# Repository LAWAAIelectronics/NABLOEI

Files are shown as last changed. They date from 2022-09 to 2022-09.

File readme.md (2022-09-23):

# ReadMe #
This repository provides:
- the full KiCad project, including gerbers plotted to the specifications of JLCPCB
- a PDF of the schematic for those who do not use KiCad
- the Arduino code
- a PNG of the user manual like bellow

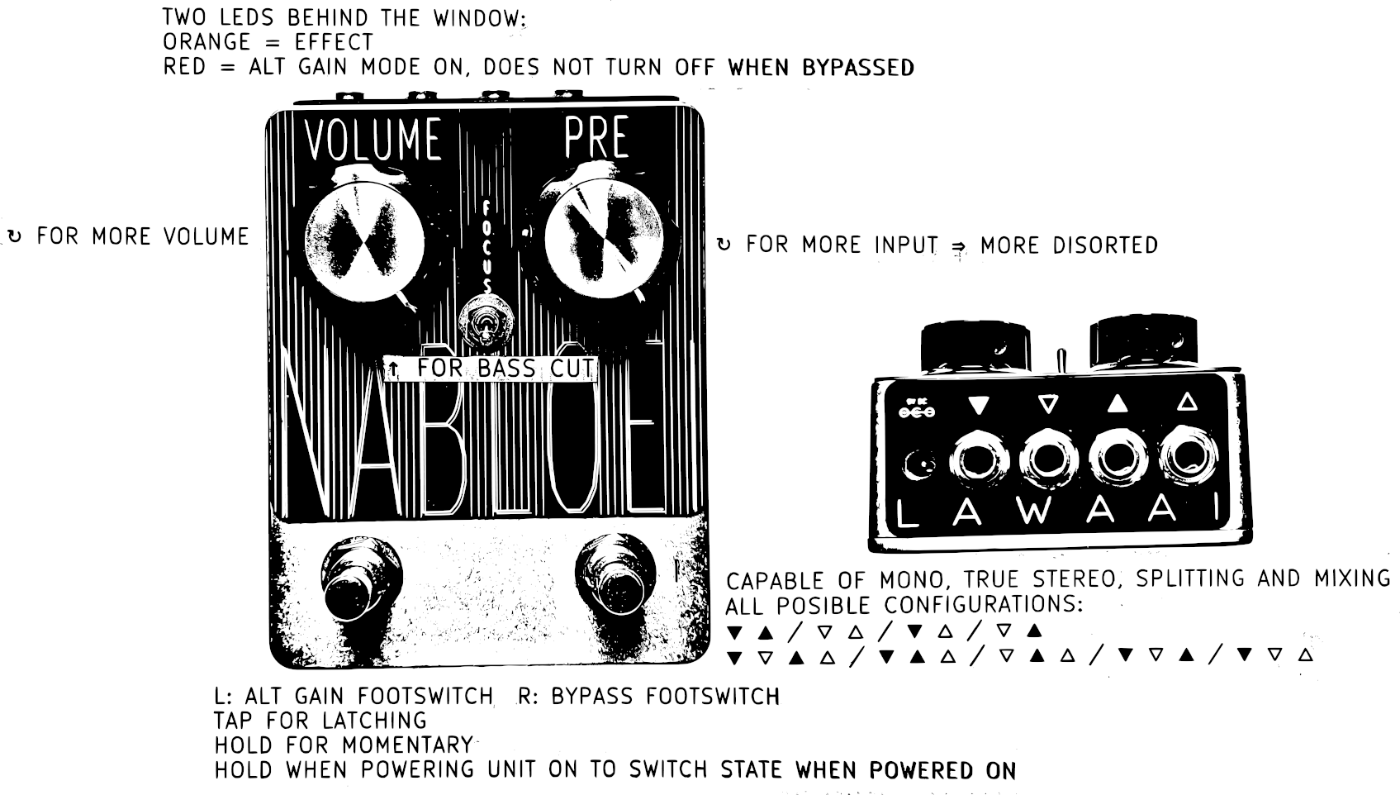
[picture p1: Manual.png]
Manual


The gerbers, pdf schematic and firmware are not located under the code tab but can be downloaded in releases.

All of this documentation is free for you to use, all I ask is that no direct copies of this pedal are made for sale.

Thank you.

LAWAAI

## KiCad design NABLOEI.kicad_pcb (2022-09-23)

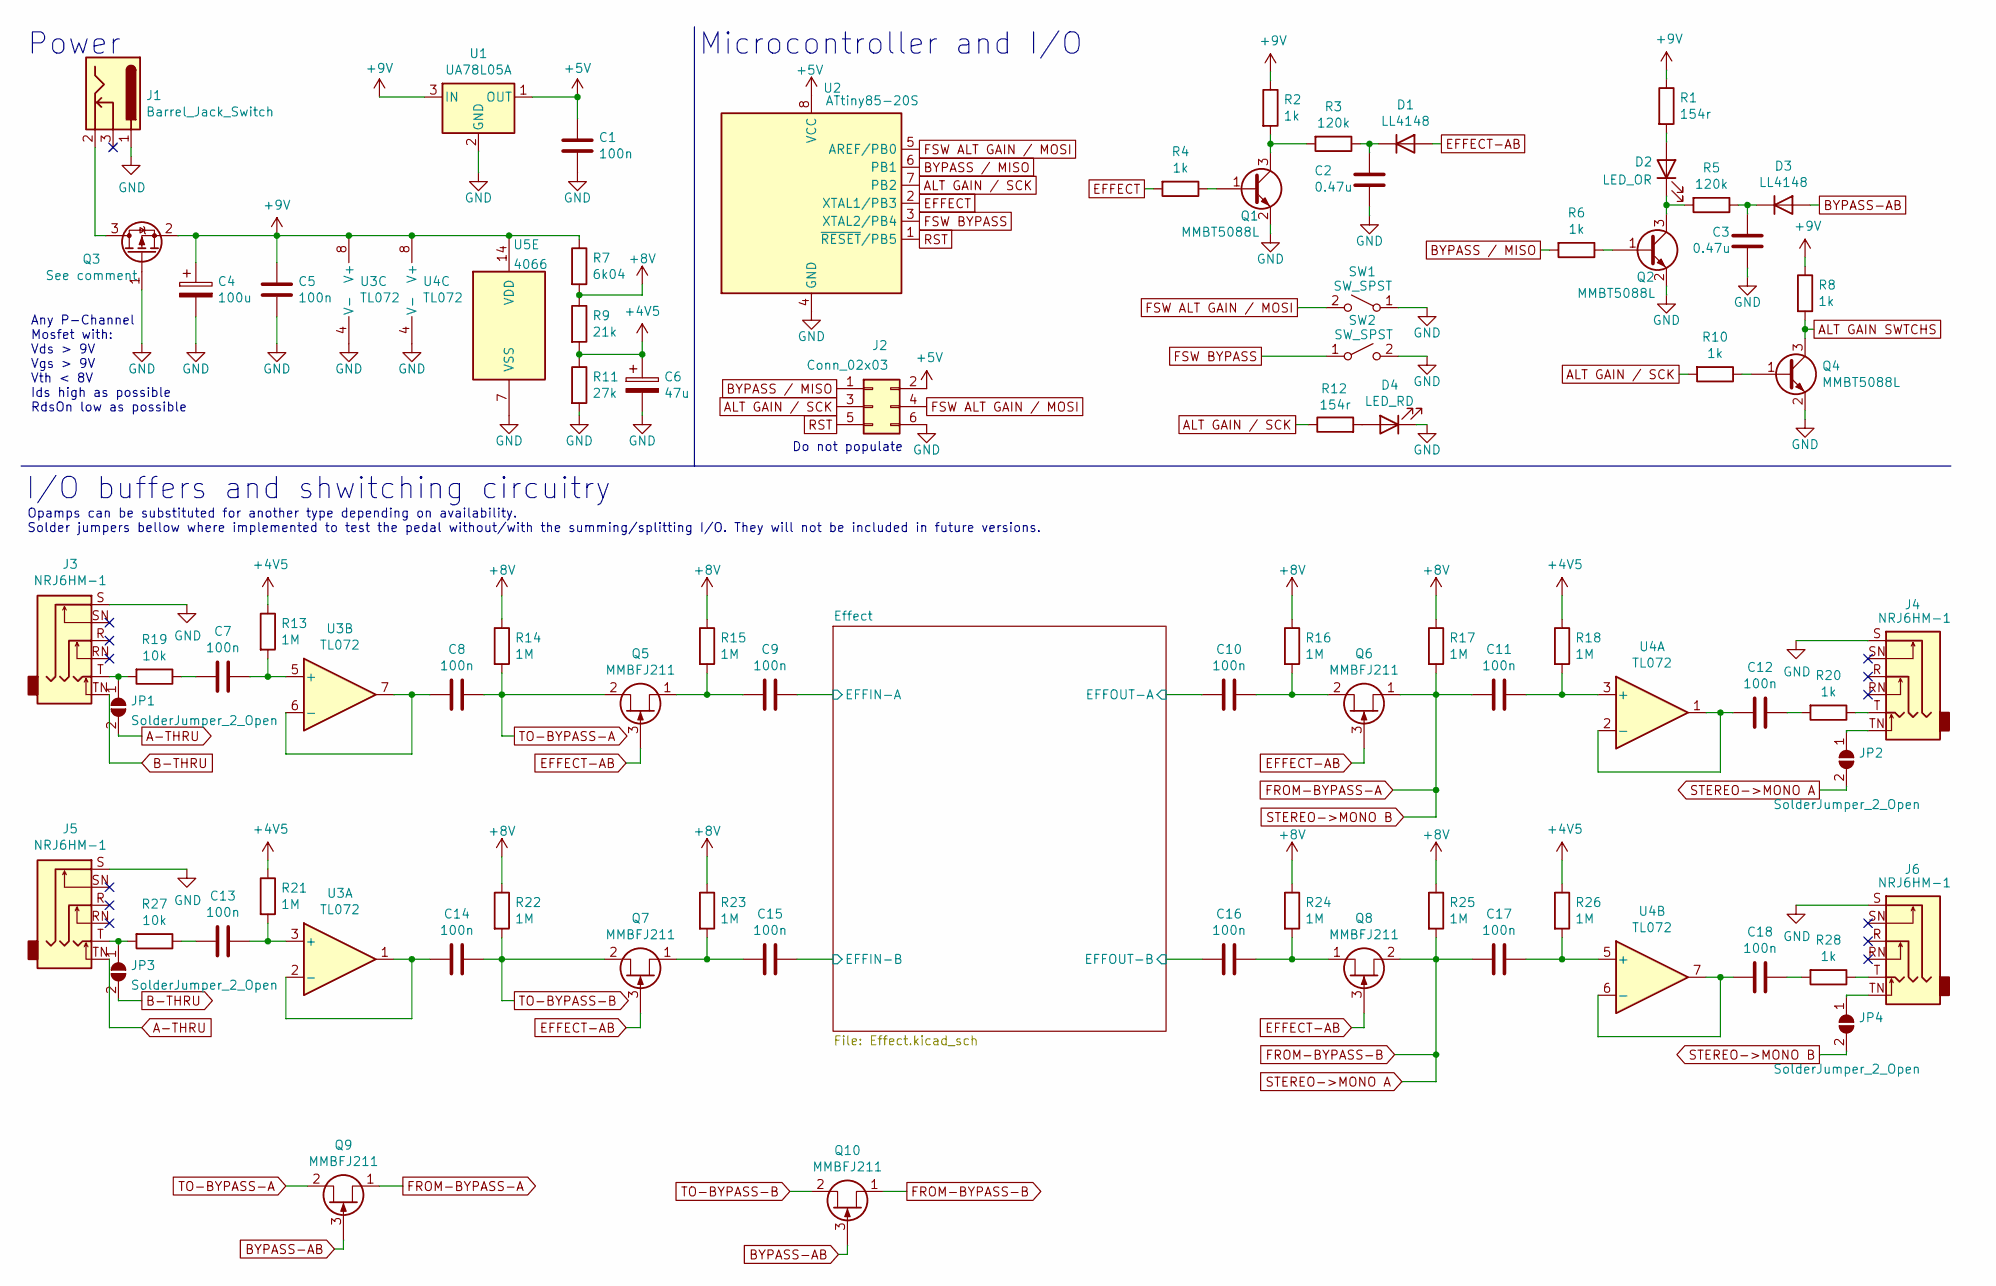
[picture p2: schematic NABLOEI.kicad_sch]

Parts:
C1, C5, C7, C8, C9, C10, C11, C12, C13, C14, C15, C16, C17, C18: 100n; C_1206_3216Metric
C2, C3: 0.47u; C_1206_3216Metric
C4: 100u; CP_Elec_8x5.4
C6: 47u; CP_Elec_5x5.4
D1, D3: LL4148; D_MiniMELF
D2: LED_OR; LED_1206_3216Metric
D4: LED_RD; LED_1206_3216Metric
J1: Barrel_Jack_Switch; BarrelJack_Horizontal
J2: Conn_02x03; PinHeader_2x03_P2.54mm_Vertical
J3, J4, J5, J6: NRJ6HM-1; Jack_6.35mm_Neutrik_NRJ6HM-1_Horizontal
JP1, JP2, JP3, JP4: SolderJumper_2_Open; SolderJumper-2_P1.3mm_Open_RoundedPad1.0x1.5mm
Q1, Q2, Q4: MMBT5088L; SOT-23
Q3: See comment; SOT-23
Q5, Q6, Q7, Q8, Q9, Q10: MMBFJ211; SOT-23
R1, R12: 154r; R_1206_3216Metric
R2, R4, R6, R8, R10, R20, R28: 1k; R_1206_3216Metric
R3, R5: 120k; R_1206_3216Metric
R7: 6k04; R_1206_3216Metric
R9: 21k; R_1206_3216Metric
R11: 27k; R_1206_3216Metric
R13, R14, R15, R16, R17, R18, R21, R22, R23, R24, R25, R26: 1M; R_1206_3216Metric
R19, R27: 10k; R_1206_3216Metric
SW1, SW2: SW_SPST; Molex_Micro-Latch_53254-0270_1x02_P2.00mm_Horizontal
U1: UA78L05A; SOT-89-3
U2: ATtiny85-20S; SOIC-8W_5.3x5.3mm_P1.27mm
U3, U4: TL072; SOIC-8W_5.3x5.3mm_P1.27mm
U5: 4066; SOIC-14_3.9x8.7mm_P1.27mm

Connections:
+4V5: C6.1, R9.2, R11.1, R13.1, R18.1, R21.1, R26.1
+5V: C1.1, J2.2, U1.1 (OUT), U2.8 (VCC)
+8V: R7.2, R9.1, R14.1, R15.1, R16.1, R17.1, R22.1, R23.1, R24.1, R25.1
+9V: C4.1, C5.1, Q3.2 (S), R1.1, R2.1, R7.1, R8.1, U1.3 (IN), U3.8 (V+), U4.8 (V+), U5.14 (VDD); also elsewhere on the board
/Effect/EFFIN-A: C9.1; also elsewhere on the board
/Effect/EFFIN-B: C15.1; also elsewhere on the board
/Effect/EFFOUT-A: C10.2; also elsewhere on the board
/Effect/EFFOUT-B: C16.2; also elsewhere on the board
A-THRU: J5.TN, JP1.2 (B)
ALT GAIN SWTCHS: Q4.3 (C), R8.2; also elsewhere on the board
ALT GAIN / SCK: J2.3, R10.2, R12.1, U2.7 (PB2)
B-THRU: J3.TN, JP3.2 (B)
BYPASS / MISO: J2.1, R6.2, U2.6 (PB1)
BYPASS-AB: D3.2 (A), Q9.3 (G), Q10.3 (G)
EFFECT: R4.2, U2.2 (XTAL1/PB3)
EFFECT-AB: D1.2 (A), Q5.3 (G), Q6.3 (G), Q7.3 (G), Q8.3 (G)
FROM-BYPASS-A: C11.2, JP4.2 (B), Q6.1 (S), Q9.1 (S), R17.2
FROM-BYPASS-B: C17.2, JP2.2 (B), Q8.2 (D), Q10.1 (S), R25.2
FSW ALT GAIN / MOSI: J2.4, SW1.2 (B), U2.5 (AREF/PB0)
FSW BYPASS: SW2.1 (A), U2.3 (XTAL2/PB4)
GND: C1.2, C2.2, C3.2, C4.2, C5.2, C6.2, D4.1 (K), J1.1, J2.6, J3.S, J4.S, J5.S, J6.S, Q1.2 (E), Q2.2 (E), Q3.1 (G), Q4.2 (E), R11.2, SW1.1 (A), SW2.2 (B), U1.2 (GND), U2.4 (GND), U3.4 (V-), U4.4 (V-), U5.7 (VSS); also elsewhere on the board
unnamed: C2.1, D1.1 (K), R3.1
unnamed: C3.1, D3.1 (K), R5.1
unnamed: C7.1, R13.2, U3.5 (+)
unnamed: C7.2, R19.1
unnamed: C8.2, U3.6 (-), U3.7
unnamed: C9.2, Q5.1 (S), R15.2
unnamed: C10.1, Q6.2 (D), R16.2
unnamed: C11.1, R18.2, U4.3 (+)
unnamed: C12.1, R20.2
unnamed: C12.2, U4.1, U4.2 (-)
unnamed: C13.1, R21.2, U3.3 (+)
unnamed: C13.2, R27.1
unnamed: C14.2, U3.1, U3.2 (-)
unnamed: C15.2, Q7.1 (S), R23.2
unnamed: C16.1, Q8.1 (S), R24.2
unnamed: C17.1, R26.2, U4.5 (+)
unnamed: C18.1, R28.2
unnamed: C18.2, U4.6 (-), U4.7
unnamed: D2.1 (K), Q2.3 (C), R5.2
unnamed: D2.2 (A), R1.2
unnamed: D4.2 (A), R12.2
unnamed: J1.2, Q3.3 (D)
unnamed: J3.T, JP1.1 (A), R19.2
unnamed: J4.T, R20.1
unnamed: J4.TN, JP2.1 (A)
unnamed: J5.T, JP3.1 (A), R27.2
unnamed: J6.T, R28.1
unnamed: J6.TN, JP4.1 (A)
unnamed: Q1.1 (B), R4.1
unnamed: Q1.3 (C), R2.2, R3.2
unnamed: Q2.1 (B), R6.1
unnamed: Q4.1 (B), R10.1
RST: J2.5, U2.1 (~RESET/PB5)
TO-BYPASS-A: C8.1, Q5.2 (D), Q9.2 (D), R14.2
TO-BYPASS-B: C14.1, Q7.2 (D), Q10.2 (D), R22.2

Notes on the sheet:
Microcontroller and I/O
Any P-Channel Mosfet with: Vds > 9V Vgs > 9V Vth < 8V Ids high as possible RdsOn low as possible
Do not populate
Opamps can be substituted for another type depending on availability. Solder jumpers bellow where implemented to test the pedal without/with the summing/splitting I/O. They will not be included in future versions.
I/O buffers and shwitching circuitry
Power

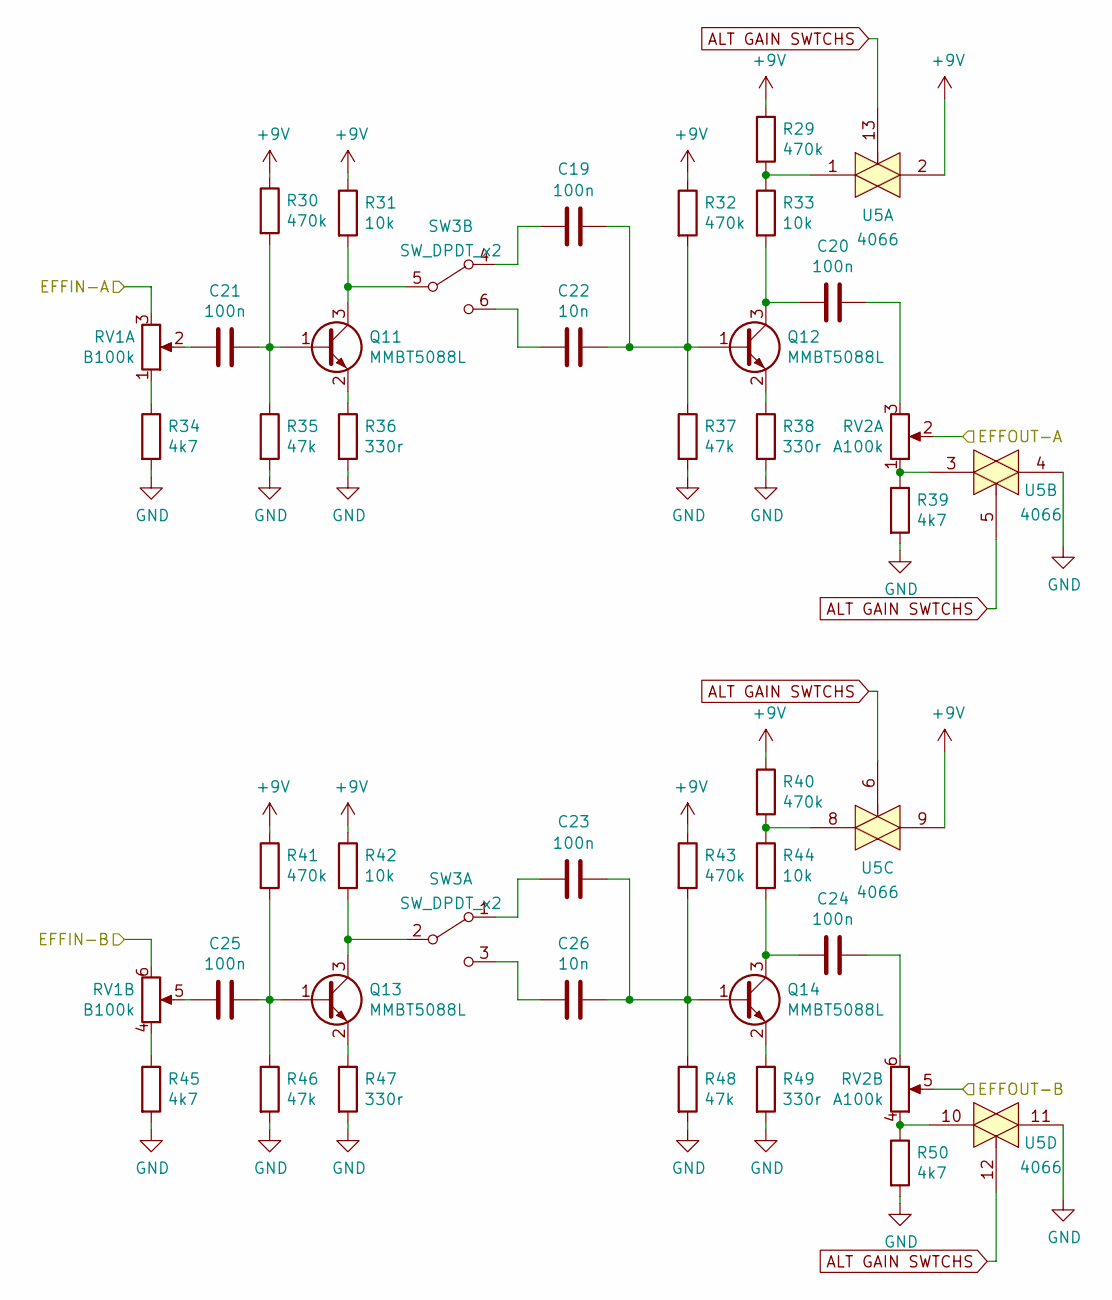
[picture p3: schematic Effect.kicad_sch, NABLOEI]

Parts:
C19, C20, C21, C23, C24, C25: 100n; C_1206_3216Metric
C22, C26: 10n; C_1206_3216Metric
Q11, Q12, Q13, Q14: MMBT5088L; SOT-23
R29, R30, R32, R40, R41, R43: 470k; R_1206_3216Metric
R31, R33, R42, R44: 10k; R_1206_3216Metric
R34, R39, R45, R50: 4k7; R_1206_3216Metric
R35, R37, R46, R48: 47k; R_1206_3216Metric
R36, R38, R47, R49: 330r; R_1206_3216Metric
RV1: B100k; Potentiometer_Alpha_RV16A01F-41-15R1_Dual_Vertical
RV2: A100k; Potentiometer_Alpha_RV16A01F-41-15R1_Dual_Vertical
SW3: SW_DPDT_x2; Switch_Dailywell_Electronics_1MD1T1B1M1QES_DPDT_ON-ON
U5: 4066; SOIC-14_3.9x8.7mm_P1.27mm

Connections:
+9V: R29.1, R30.1, R31.1, R32.1, R40.1, R41.1, R42.1, R43.1, U5.2, U5.9; also elsewhere on the board
/Effect/EFFIN-A: RV1.3; also elsewhere on the board
/Effect/EFFIN-B: RV1.6; also elsewhere on the board
/Effect/EFFOUT-A: RV2.2; also elsewhere on the board
/Effect/EFFOUT-B: RV2.5; also elsewhere on the board
ALT GAIN SWTCHS: U5.5, U5.6, U5.12, U5.13; also elsewhere on the board
GND: R34.2, R35.2, R36.2, R37.2, R38.2, R39.2, R45.2, R46.2, R47.2, R48.2, R49.2, R50.2, U5.4, U5.11; also elsewhere on the board
unnamed: C19.1, C22.1, Q12.1 (B), R32.2, R37.1
unnamed: C19.2, SW3.4 (A)
unnamed: C20.1, RV2.3
unnamed: C20.2, Q12.3 (C), R33.2
unnamed: C21.1, Q11.1 (B), R30.2, R35.1
unnamed: C21.2, RV1.2
unnamed: C22.2, SW3.6 (C)
unnamed: C23.1, C26.1, Q14.1 (B), R43.2, R48.1
unnamed: C23.2, SW3.1 (A)
unnamed: C24.1, RV2.6
unnamed: C24.2, Q14.3 (C), R44.2
unnamed: C25.1, Q13.1 (B), R41.2, R46.1
unnamed: C25.2, RV1.5
unnamed: C26.2, SW3.3 (C)
unnamed: Q11.2 (E), R36.1
unnamed: Q11.3 (C), R31.2, SW3.5 (B)
unnamed: Q12.2 (E), R38.1
unnamed: Q13.2 (E), R47.1
unnamed: Q13.3 (C), R42.2, SW3.2 (B)
unnamed: Q14.2 (E), R49.1
unnamed: R29.2, R33.1, U5.1
unnamed: R34.1, RV1.1
unnamed: R39.1, RV2.1, U5.3
unnamed: R40.2, R44.1, U5.8
unnamed: R45.1, RV1.4
unnamed: R50.1, RV2.4, U5.10

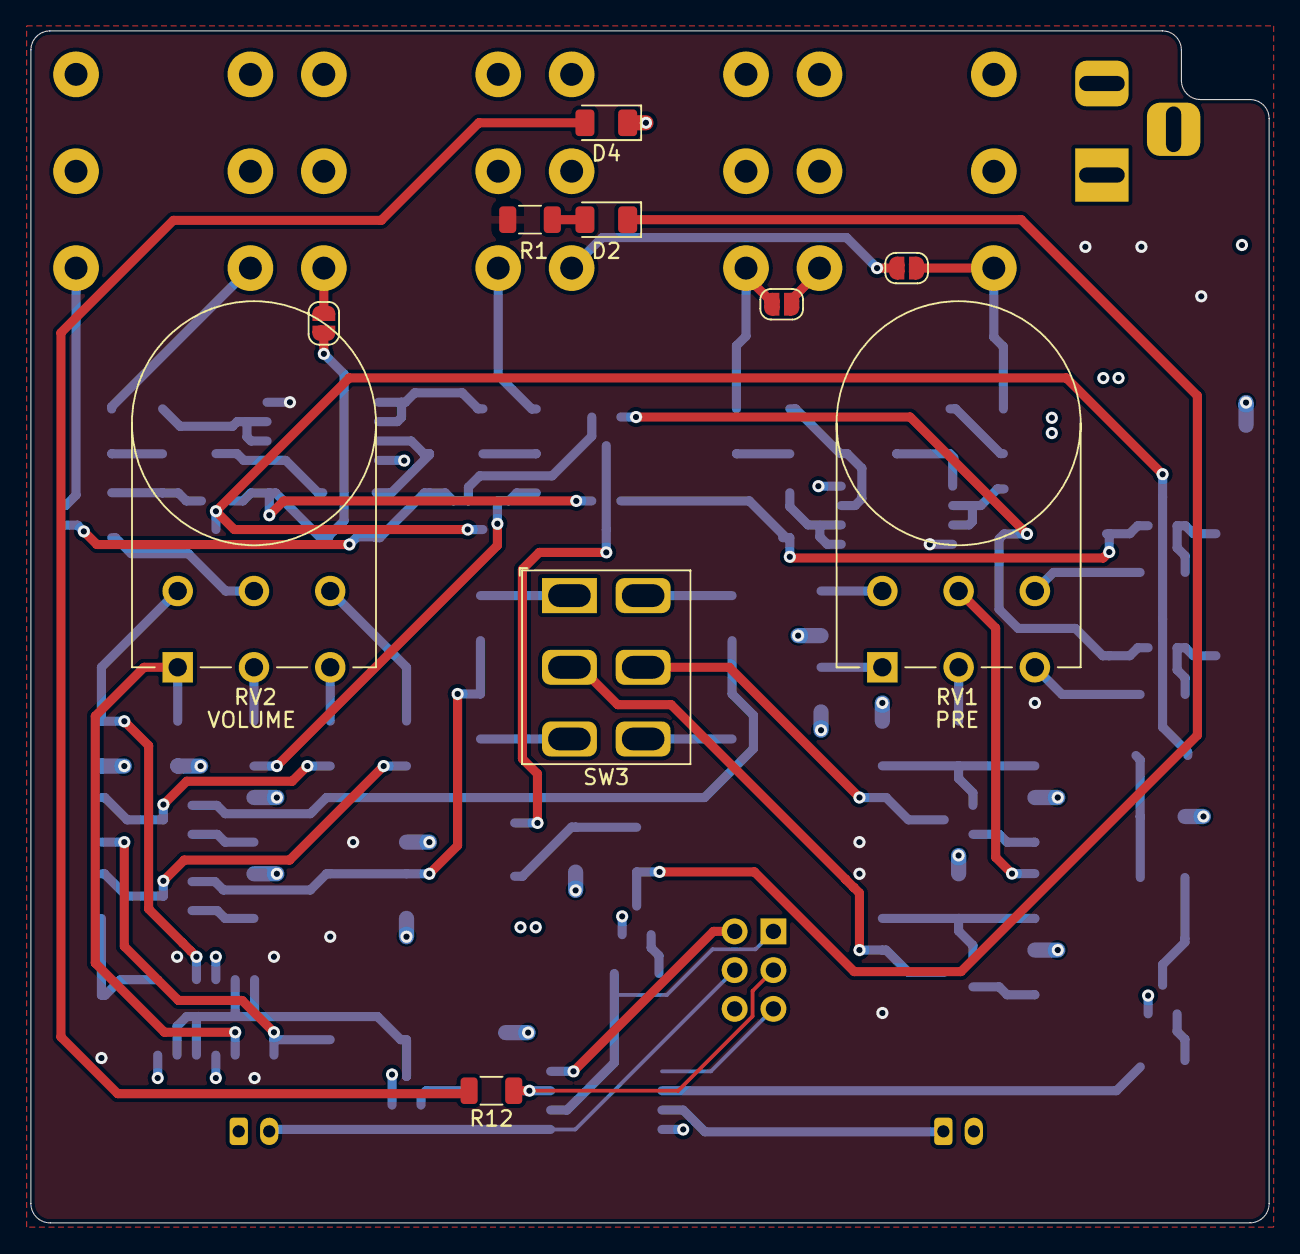
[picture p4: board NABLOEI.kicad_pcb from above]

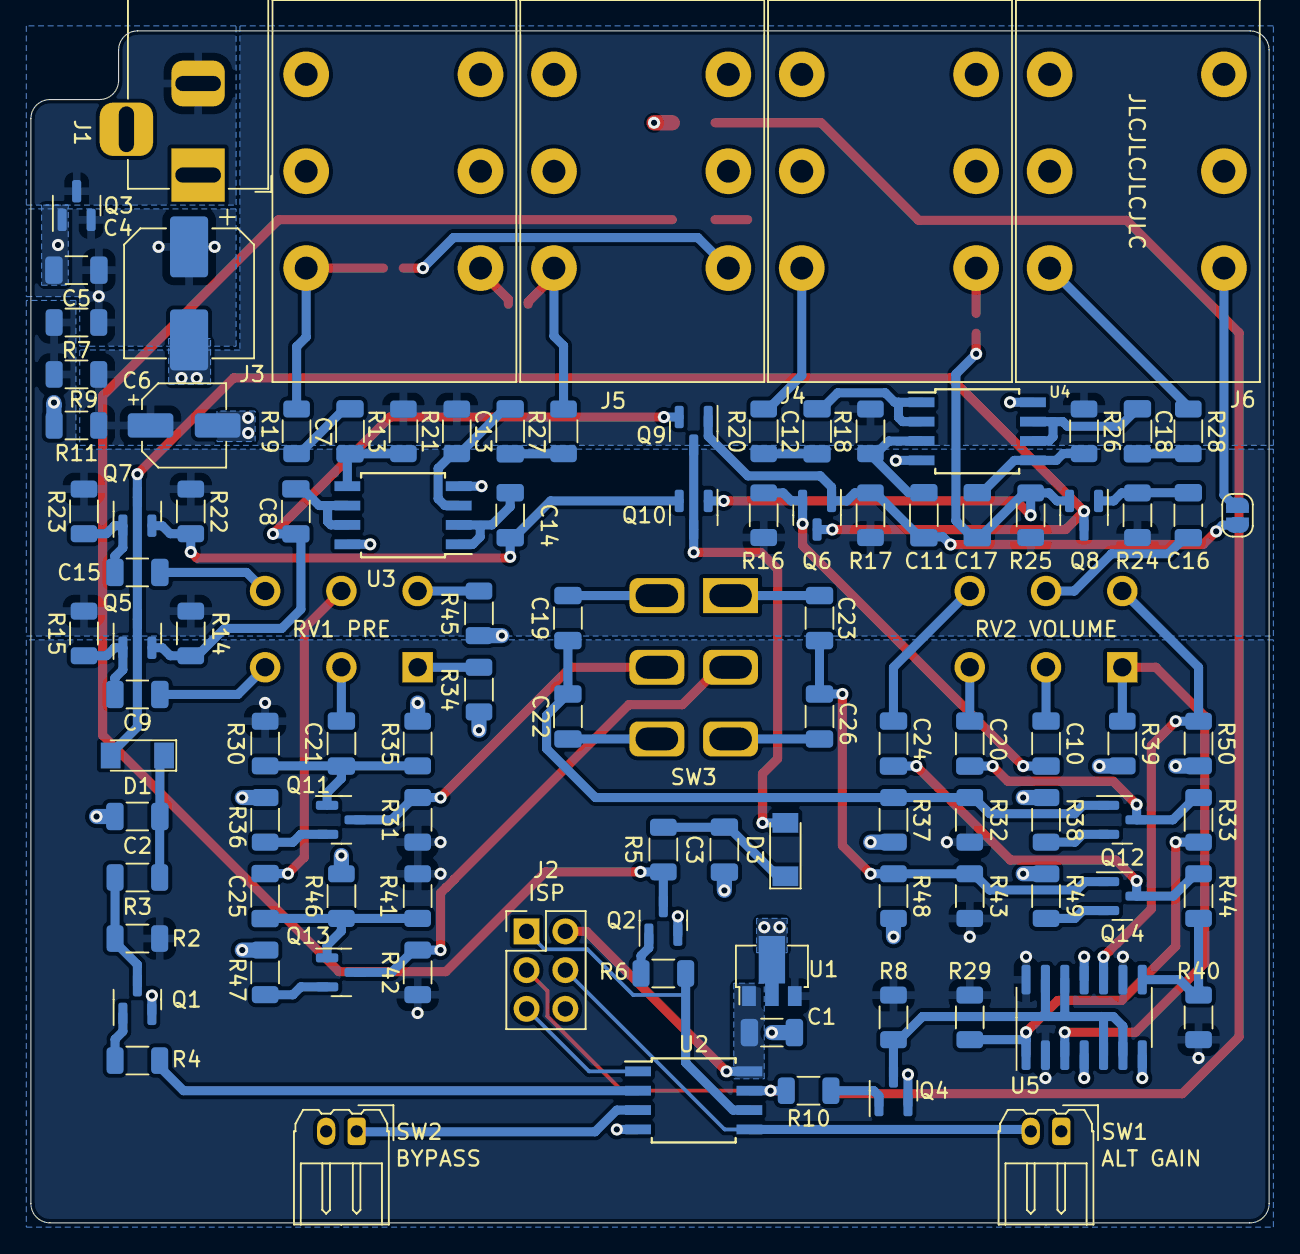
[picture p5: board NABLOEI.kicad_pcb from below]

Board: 4 copper layers, 81.2 x 78.1 mm, 114 parts (104 on the bottom side), 82 nets.
